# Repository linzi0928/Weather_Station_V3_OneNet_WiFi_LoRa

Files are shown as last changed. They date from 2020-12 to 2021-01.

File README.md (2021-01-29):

# Weather_Station_V3_OneNet_WiFi_LoRa
STM32+ESP8266+SX1278+Onenet的户外气象站制作
================
中文版制作教程请下拉。   
This repository contains all design files for an outdoor weather station. It can detect temperature, humidity, atmospheric pressure, TVOC, CO2, PM2.5, UV intensity and its own voltage. Then it can upload these parameters to the OneNet IoT platform through Wifi and http protocols. At the same time, it also provides the source code of an Android APP which can connect the OneNet platform and show these parameters.  
The design is divided into three parts:  
* Outdoor Data Collector
* Indoor Data Display&Uploader
* Android APP  
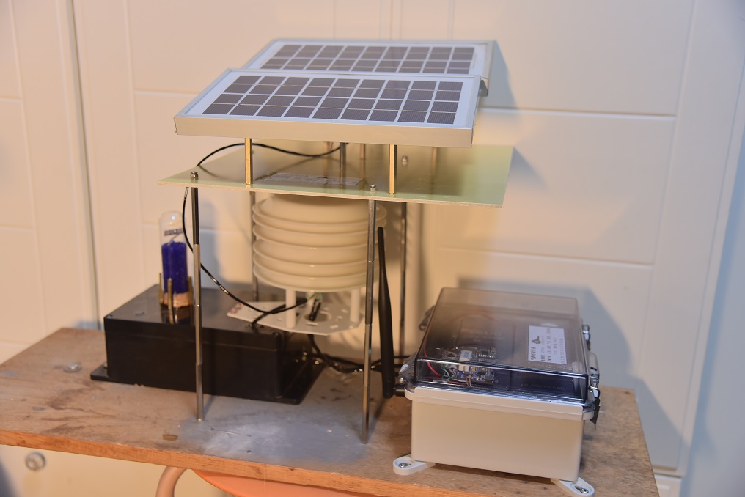
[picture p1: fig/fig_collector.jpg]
Data Collector
  
# Outdoor Data Collector  
This is the most important part of this design. Sensors and controllers are as follows:  
* STM32L051C8T6 as main controller.  
* SX1278 sends data to the indoor uploader.  
* Two LS Ultra Capacitor 2.8V 3000F in serial to storage the power.  
* Two 9V 3Watts Solar Panels in parallel to power up the whole system.  
* BME680 to get temperature, humidity and atmospheric pressure.  
* SGP30 to get CO2 and TVOC.  
* VEML6070 to get UV intensity.  
* ZPH02 to get PM2.5.  
* ESP8266 to upload the data directly (Optional)  
**Schematic of Data Collector**  
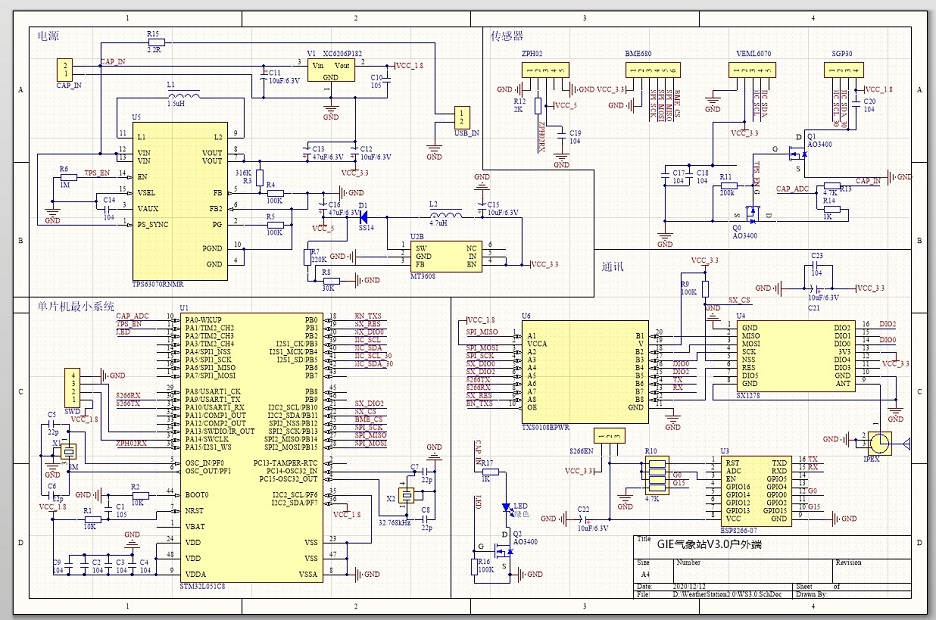
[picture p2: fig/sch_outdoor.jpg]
Schematic of Data Collector
  
**STEP 1 Collect ALL Materials!**  
Use Altium Designer to open the PCB project and check if the circuit is suitable for you. If you don't want any changes, you can directly submit the .PcbDoc files to the factory. And then compare the schematic diagram and the BOM(bill of materials) exported by AltiumDesigner to purchase components. Except the components in the BOM, you also need these:  
LS Ultra Capacitor 2.8V 3000F with protection board x2  
Outdoor waterproof box made by ABS or other reliable materials 160x210x100mm x1  
Test Tube 30x100mm(For installing UV sensor) x1  
Desiccant(For filling the test tube)  
Resin waterproof agent  
Venetian box for weather station  
M4 screws and nuts  
M4 60+6mm Stainless steel column x25  
PG7 waterproof head  x3  
Fiberglass board 300 mm * 300 mm * 3 mm x1  
Waterproof resin  
Wires and other small things  
**STEP 2 Complete the Welding of the Circuit**  
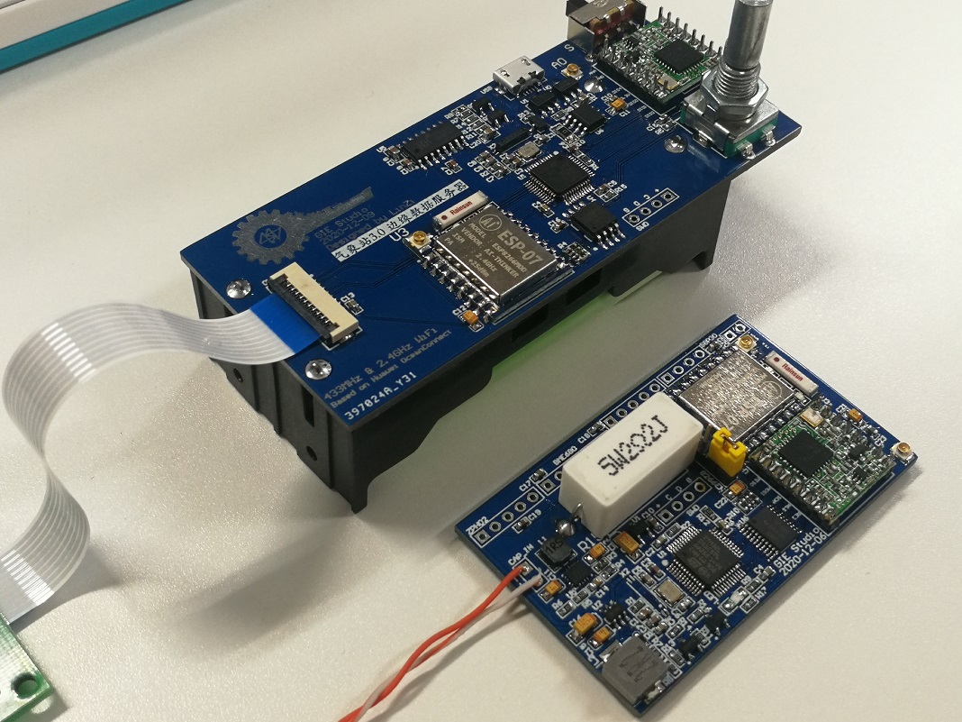
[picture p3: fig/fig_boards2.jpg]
PCBs of two part of this project
  
There is no special process for outdoor data-collector welding. The specific parameter of each component can be obtained by look at the schematic diagram.We recommend welding the chips, resistors and capacitors at first, then welding higher components, and finally welding the plug-ins, which can make the welding process more convenient.After the welding is completed, power on to test whether it is working properly. Normally, there will be abnormal work caused by improper welding.  
**STEP 3 Assembly**  
First, make four holes on the side of the box.Three of them are used to install the PG7 waterproof head and one is used to install the antenna.Be sure the holes have the right diameter.  
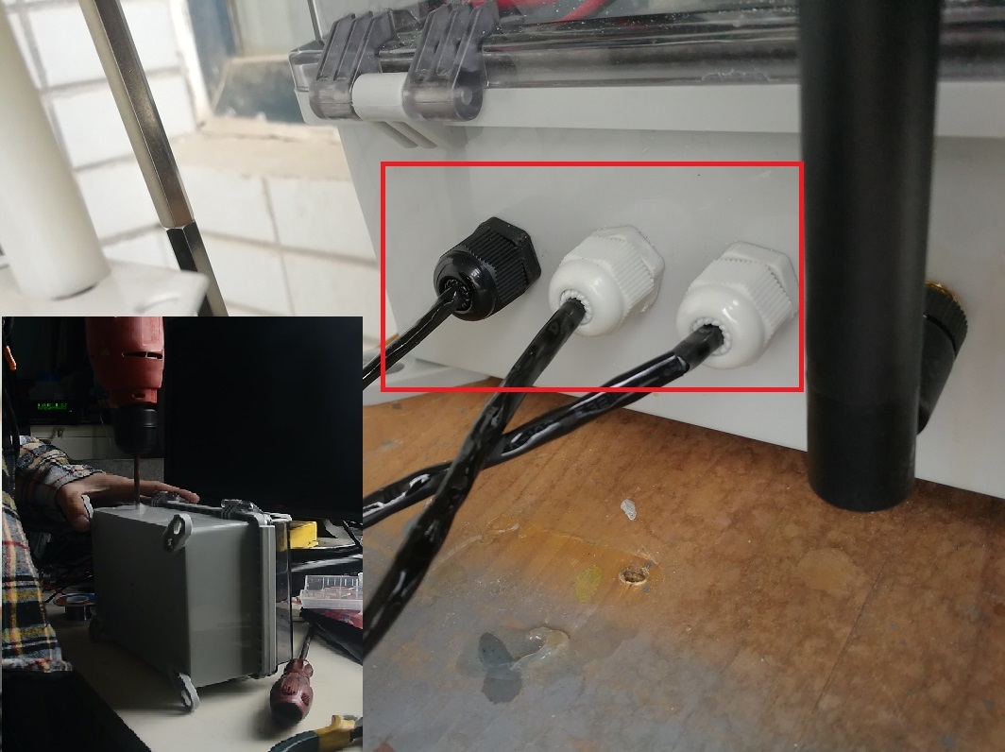
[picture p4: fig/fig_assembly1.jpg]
Make holes at the side of the box
  
Then install the protection board of the ultra capacitor and lead out the wire, and then put it into the box. Next fill up the gap between the capacitor and the box with anything you can find.     
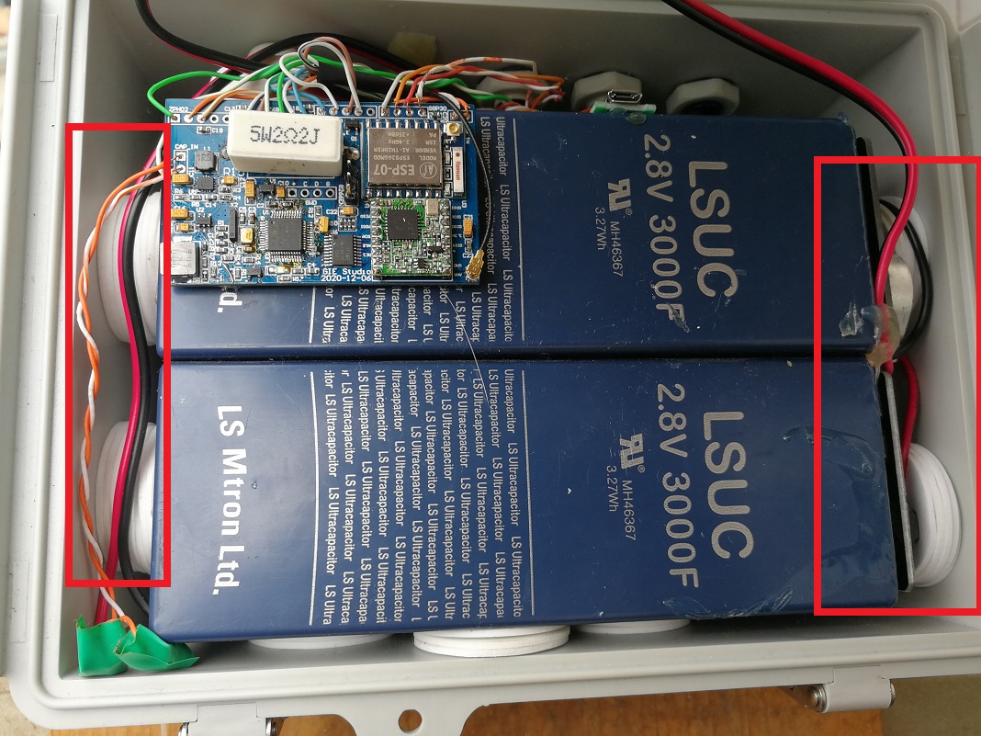
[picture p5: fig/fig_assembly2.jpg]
Install two capacitors and fill up the gap
    
Find a suitable base-plate and fix the box to it. I used a scrap wooden board as the base-plate. Then fill up the test tube using desiccant and put the wired-up UV sensor into it. Then put the PM2.5 sensor(ZPH02), BME680, SGP30 into the venetian box.  
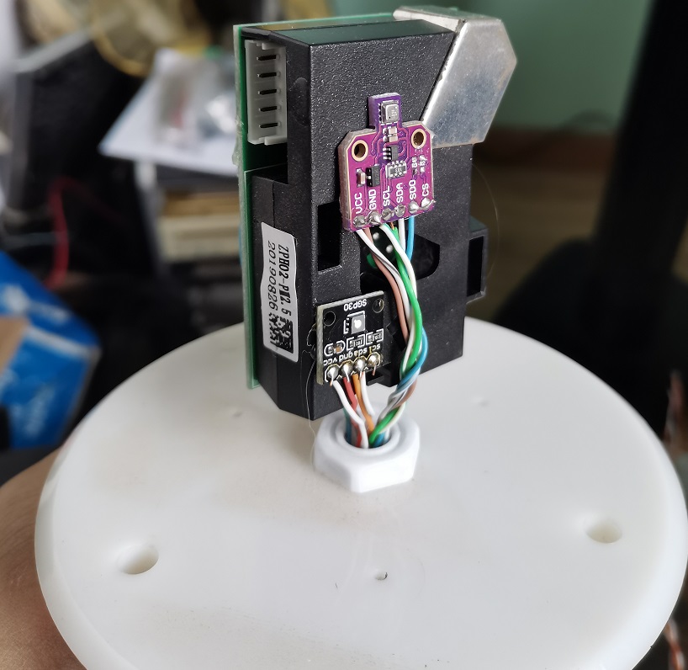
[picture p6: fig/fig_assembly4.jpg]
Install ZPH02, BME680, SGP30 into the venetian box
   
Install the test tube and the venetian box on the base-plate. In order to facilitate the installation, some things can be used to pad. For example, I used the black box left by the previous generation weather station to pad the sensors.  
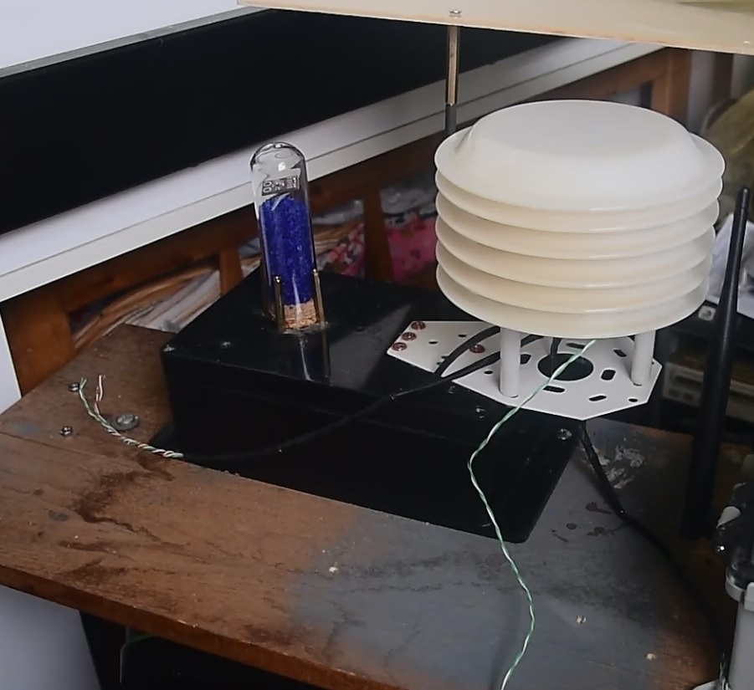
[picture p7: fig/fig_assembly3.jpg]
Install the UV sensor and venetian box
  
Then use stainless steel column to put up the fiberglass board to cover the venetian box. This is to prevent direct sunlight from interfering with the sensors in the venetian box. Finally, install the solar panel above the fiberglass board and fix it with stainless steel column. The output of the solar panel is directly paralleled to the two ends of the capacitor through a 1N5819 diode.    
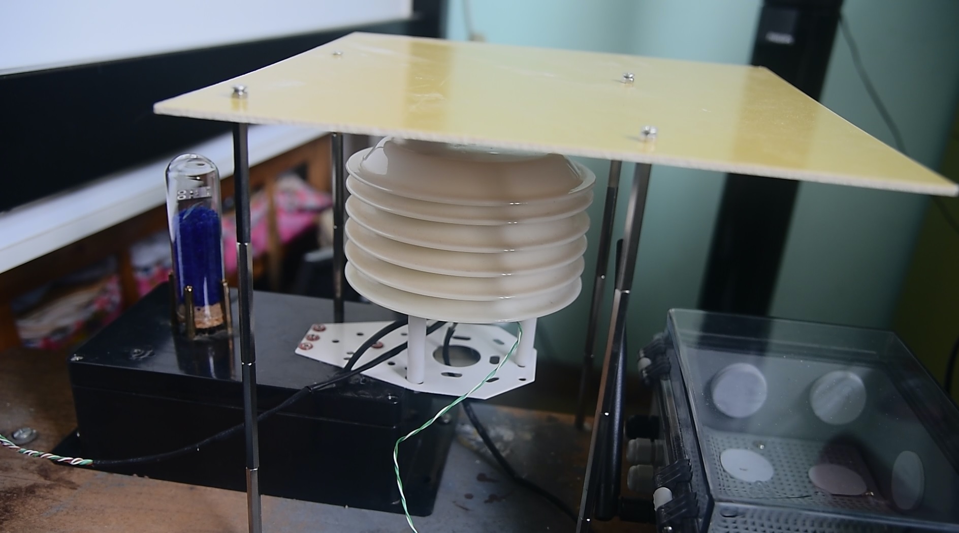
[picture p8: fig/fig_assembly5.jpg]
Install the Fiberglass board
  
**STEP 4 Program and Debug**  
Notice: Because STM32 works under 1.8V voltage in this design, you need to download the program use the full version of JLINK.  
The program is created on the MDK521 using CUBE MX. The data collector and the uploader are connected by sx1278 in 433MHz frequency band.In order to save power, when the collector completes a data acquisition of sensors, it will pack all the data and send it in 433MHz frequency band only once. So the uploader needs to listen all the time to avoid missing packets.The communication protocol between collector and uploader is shown in the chart below.  

|  Byte  | 0-3 | 4-7 | 8-11 | 12-15 | 16-16 | 17-20 | 21-22 | 23-24 | 25-26 | 27-30 |
| :----: | :----: | :----: | :----: | :----: | :----: | :----: | :----: | :----: | :----: | :----: |
| Content | Temperature | Humidity | Pressure | Gas resistance | VOC Level | PM2.5 | UV | CO2 | TVOC | Voltage |
| Type | Float | Float | Float | Float | u8 | u32 | u16 | u16 | u16 | Float |
  
# Indoor Data Display&Uploader
This part of this design can recieve data packages from the outdoor collector. And then upload these data to OneNet using http protocol. In addition, the data can be stored in  128Mbit memory and displayed on a 256x64 OLED screen in real time. After connecting to the computer through USB, the data can be exported through serial port. Controller and other components are as follows:  
* STM32F103CBT6 as main controller.  
* SX1278 receive data from the outdoor collector.  
* Two 18650 lithium batteries to storage the power.    
* ESP8266 to connect the OneNet platform.  
* 256x64 OLED screen to display the data.  
* CH340C to connect the computer.  
* 25Q128 flash to store the data.  
* 3D printing shell.  
**Schematic of Data Uploader**  
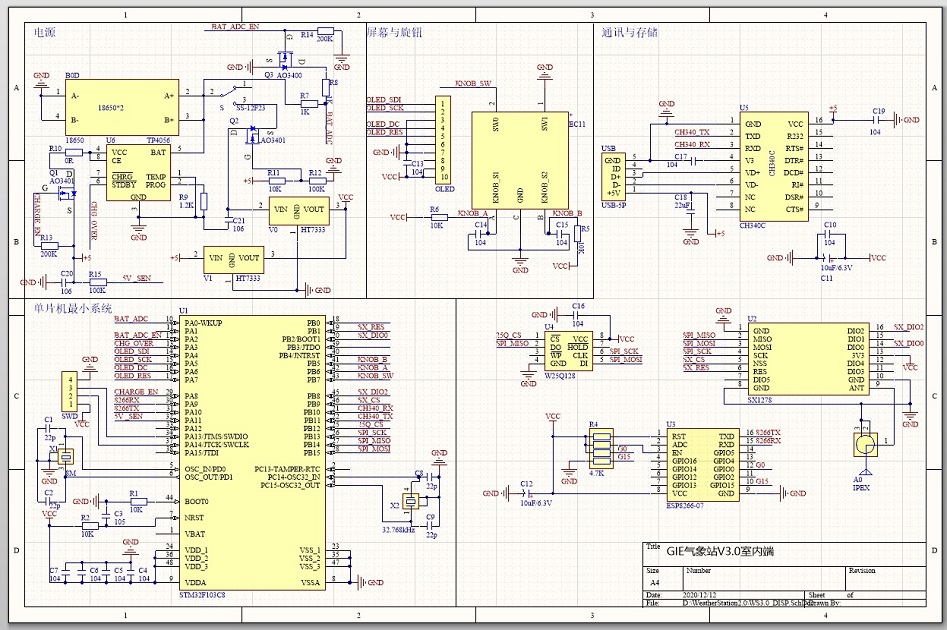
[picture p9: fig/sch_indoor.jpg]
Schematic of Data Uploader
  
**STEP 1 Collect ALL Materials!**  
The steps to export BOM are the same as before. In addition to the materials in the BOM, the following items need to be prepared:  
18650 lithium battery x2  
256x64 OLED screen x1  
IPEX-SMA cable x2  
Knob handle for ec11 x1  
10pin 1mm 10cm reverse FPC cable  x1  
3D printing shell(design file also in this repository  
M3 screws and nuts  
Dupont lines  
**STEP 2 Complete the Welding of the Circuit**  
Same as the data-collector...  
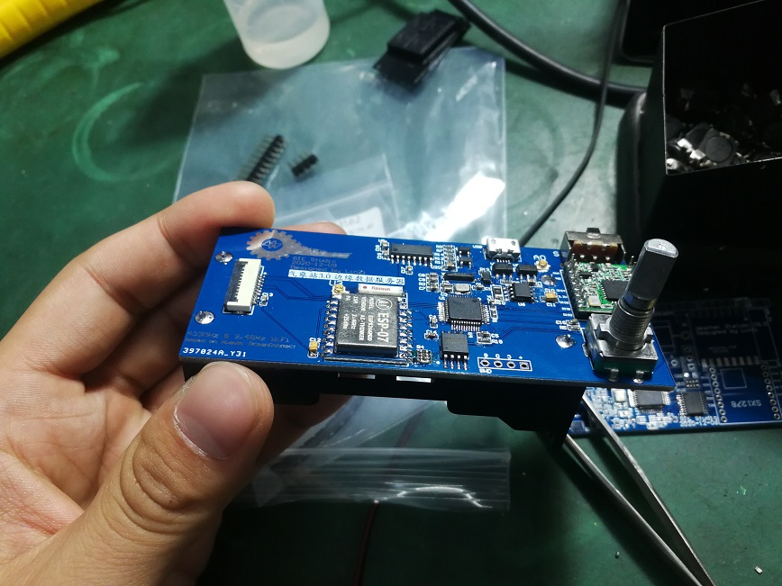
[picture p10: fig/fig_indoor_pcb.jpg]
PCB of indoor uploader
  
**STEP 3 Program and Debug**  
Same as the data collector, the program is also created on the MDK521 use CUBE MX and we also recommend using JLINK to download and debug the program. If you do not want to add or remove any functions, you can directly download the program into the microcontroller.  
Wifi name, password and various information required to access the OneNet platform can be written through the USB serial port using AT command.Use a micro usb cable to connect the computer and the uploader. If you are using this kind of USB serial port for the first time, you may need to install the CH340 driver.Then open a serial port assistant and select the port number that the uploader is connected to. Then you can send AT commands through serial port assistant to write configuration information.All available AT commands are shown below(Note: All commands need to end with a newline (\r\n)):  
* AT+EXP  
This command is used to query and export the weather information stored in the uploader.  
Using AT+EXP?, you can query the storage address of the latest data. The address indicates the location where the weather information is stored in the flash, starting from 0x10000 (0x00000-0x10000 are reserved for storing configuration information). Each time a piece of weather information is stored, the address will increase by 64 bytes, which is Hexadecimal 0x40, for example, when the first message is stored, the latest address will change from 0x10000 to 0x10040, and so on.  
Using AT+EXP=<addr> you can export all weather information starting from this address to the latest. If addr=10000, all weather information can be exported.(Example: AT+EXP=10000)  
* AT+ERS  
This command can be used to erase all weather information. For safety, you need to type and send this command twice to complete the deletion.  
* AT+CWJAP  
This command can be used to configure the ssid and password of the Wifi connected to the uploader.  
Using AT+CWJAP=<WiFi SSID>,<WiFi password> to achieve it. For example:AT+CWJAP=TP-Link-xxx,88888888. Note that the SSID cannot be longer than 21 letters, and the password cannot be longer than 20 letters, otherwise the configuration will fail.  
* AT+CMSET  
This command can be used to set the access information of the OneNet platform.  
Using AT+CMSET=<dev_id>,<API-key> to achieve it. For example:AT+CMSET=657284563,SkFGTtTMpEFf=xG580jwowTZ9r0=.
  
**STEP 4 Assembly**  
Because it is not easy to modify the circuit or program after assembly, we recommend installing it into the shell after debugging.You can paint the shell to your desired color before assembling if you like. In addition, you can also use the DuPont cable to lead the debug port to the side of the circuit board, so that you can easily modify the program even after assembly.  
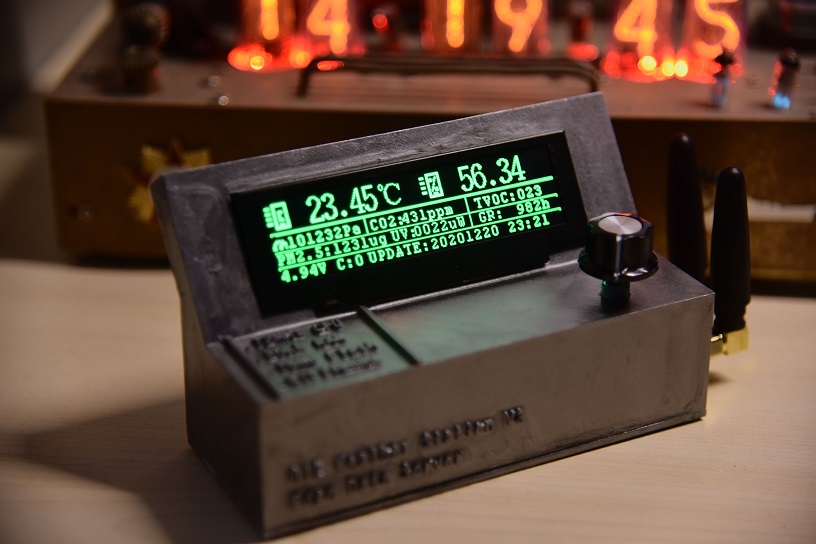
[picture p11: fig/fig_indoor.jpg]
indoor uploader
  
The first step in assembly is to install the screen. First, insert the FPC cable into the screen, and then fold the FPC into a 90-degree angle so that it can be drawn out from the side. Then put the screen into the shell diagonally upwards, so that the PCB of the screen is stuck in the gap at the top of the shell and allow the screen expose completely. Then use hot melt glue to simply fix the bottom and sides of the screen.  
Then insert the circuit board with the battery into the shell. After installing the back plate, the assembly is complete.
# Android APP
This APP can connect the OneNet and get the data. It is built on Android Studio. Please understand that it only has Chinese version currently.
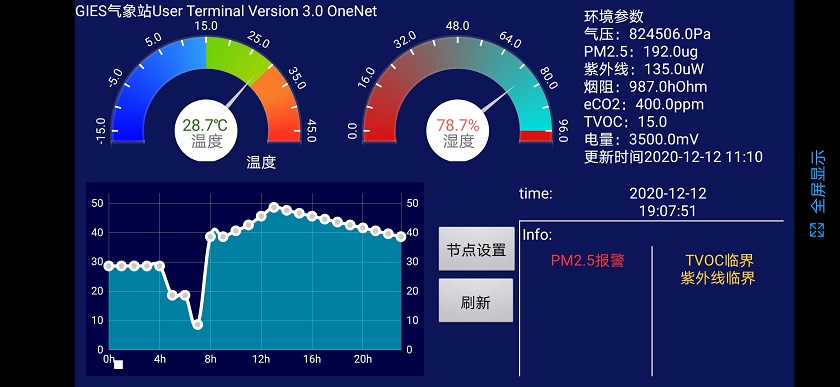
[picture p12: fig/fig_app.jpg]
APP
  
#
STM32+ESP8266+SX1278+Onenet的户外气象站制作
=============
此仓库包含室外气象站的所有设计文件。可检测温度、湿度、大气压、TVOC、CO2、PM2.5、紫外线和自身电压。然后可以通过Wifi和http协议将这些参数上传到中国移动OneNet物联网平台。同时还提供了一个Android APP的源代码，可以从OneNet平台获取气象站的数据。  
设计分为三部分：
* 室外数据采集器  
* 室内数据显示上传器  
* Android应用程序  
Data Collector  
# 户外采集端  
户外采集端是本设计的主体部分，传感器和控制器如下：
*主控制器STM32L051C8T6  
*SX1278发送数据到室内中继  
*两个串联的LSUC的超级电容2.8V 3000F  
*两块9伏3瓦的太阳能电池板并联为整个系统供电  
*BME680获得温度、湿度和大气压  
*SGP30获取CO2和TVOC  
*VEML6070获取紫外线强度  
*ZPH02获取PM2.5  
*ESP8266直接上传数据（可选）  
**户外采集端原理图**  
Schematic of Data Collector  
**步骤一 收集材料**  
使用Altium Designer打开PCB项目，检查电路是否合适。如果不想做任何更改，可以直接将.PcbDoc文件发到淘宝上做pcb的厂家。然后使用AltiumDesigner导出的元器件清单（BOM）采购元件。除此之外，还需要如下零部件：  
LSUC超级电容2.8V 3000F，以及保护板  x2  
户外防水盒160x210x100mm x1  
试管30x100mm（用于安装紫外线传感器）x1  
干燥剂（用于填充试管）  
树脂防水剂  
气象站用百叶盒子  
M4螺丝和螺母
M4 60+6mm不锈钢柱x25
PG7防水头x3  
玻璃纤维板 300x300x3 mm x1  
PCB保护树脂
电线和其他小零件  
**步骤二 电路焊接**  
PCBs of two part of this project  
焊接上没什么好说的，每个元件的具体型号可以通过查看原理图获得。建议先焊接芯片、电阻、电容，再焊接较高的元器件，最后焊接插件，这样可以使焊接过程更加方便。然后通电测试是否正常工作，一般情况下都会有焊接不当导致的异常。  
**步骤三 组装**  
首先，在防水盒的侧面打四个孔，其中的三个用于安装PG7防水头，一个用于安装天线，根据具体情况决定孔的正确直径。  
Make holes at the side of the box  
然后装上超级电容的保护板，引出导线，然后放入盒内，用你能找到的任何东西填满电容和盒子之间的空隙。   
Install two capacitors and fill up the gap    
找一个合适的底板，把盒子固定在上面。我用了一块废木板做的底板。然后将燥剂倒入试管，并将连接好的紫外线传感器放入试管中，然后将PM2.5传感器（ZPH02）、BME680、SGP30放入百叶盒。   
Install ZPH02, BME680, SGP30 into the venetian box   
将试管和百叶盒安装在底板上。为了便于安装，有些东西可以用来垫，比如我这里用上一代气象站留下的黑盒子来把这俩垫起来。  
Install the UV sensor and venetian box  
为了防止阳光直射干扰百叶盒中的传感器，需要用不锈钢柱搭玻璃纤维板盖住百叶盒。然后将太阳能板安装在玻璃纤维板上方，并用不锈钢柱固定，太阳能电池板的输出通过一个1N5819二极管直接并联到电容的两端。最后用放水树脂将所有可能漏水、腐蚀的地方涂好即可。  
Install the Fiberglass board  
**步骤四 程序下载与调试**  
注意：由于本设计中STM32工作在1.8V电压下，因此需要使用完整版的JLINK下载程序。
程序是使用CubeMX在MDK521上创建的。户外采集端和室内中继以433MHz频段sx1278通信，为了省电，当采集端完成传感器的数据采集后只会在433MHz频段发送一次，所以室内中继端需要一直监听以避免遗漏包。采集器和上传器之间的通信协议如下表所示。

|  字节  | 0-3 | 4-7 | 8-11 | 12-15 | 16 | 17-20 | 21-22 | 23-24 | 25-26 | 27-30 |
| :----: | :----: | :----: | :----: | :----: | :----: | :----: | :----: | :----: | :----: | :----: |
| 内容 | 温度 | 湿度 | 气压 | 烟阻 | VOC等级 | PM2.5 | 紫外线 | 二氧化碳 | TVOC | 电压 |
| 类型 | Float | Float | Float | Float | u8 | u32 | u16 | u16 | u16 | Float |  
# 室内数据中继与显示端
这部分设计可以接收来自室外采集端的数据包。然后使用http协议将这些数据上传到OneNet。此外，数据还将存储到128Mbit闪存中，并实时显示在256x64的oled屏幕上，通过USB连接到计算机后，可以通过串口导出数据。控制器及其它部件方案如下：  
* STM32F103CBT6为主控  
* SX1278从室外采集端接收数据  
* 两个18650锂电池供电  
* ESP8266连接OneNet平台  
* 256x64 OLED屏幕显示数据  
* CH340C连接电脑  
* 25Q128闪存存储数据  
* 3D打印外壳  
**室内数据中继端原理图**  
Schematic of Data Uploader  
**步骤一 收集材料**  
导出BOM表的步骤与前面相同。除了BOM表中的材料外，还需要准备以下元件：  
18650 锂电池 x2  
256x64 OLED 屏幕 x1  
IPEX-SMA 转接线 x2  
ec11旋钮帽 x1  
10pin 1mm 10cm 反向 FPC线  x1  
3D 打印外壳（设计文件同样在仓库中）  
M3螺丝与螺母  
母对母杜邦线  
**步骤二 电路焊接**  
与数据采集端相同...  
PCB of indoor uploader  
**步骤三 程序下载与调试**  
与数据采集器相同，该程序也是在MDK521上创建的，使用cubemx，建议使用JLINK下载和调试该程序。如果不想添加或删除任何功能，可以直接将程序下载到微控制器中。    
Wifi名称、密码和访问OneNet平台所需的各种信息都可以通过USB串口AT命令修改，用micro USB线连接电脑，如果是第一次使用这种USB串口，可能需要安装CH340驱动，然后打开串口调试助手并选择连接到的端口号，然后就可以通过串口助手发送AT命令来修改配置了。全部可用的AT命令如下所示（注意：所有命令都需要以换行符（\r\n））结尾：  

* AT+EXP  
此命令用于查询和导出数据中继端中存储的天气信息。  
使用AT+EXP?，可以查询最新数据的存储地址，地址指示天气信息存储在闪存中的位置，从0x10000开始（0x00000-0x10000保留用于存储配置信息），每次存储一条天气信息时，地址都会增加64个字节，即十六进制的0x40，例如存储第一条信息时，最新地址会从0x10000变为0x10040，以此类推。  
使用AT+EXP=<addr>可以将从该地址开始的所有天气信息导出。如果addr=10000，则可以导出所有天气信息（例如：AT+EXP=10000）  
  
* AT+ERS  
此命令可用于删除所有天气信息。为了安全起见，需要并发送此命令两次以完成删除。  
  
* AT+CWJAP
此命令可用于配置连接Wifi的名称和密码。  
使用AT+CWJAP=<WiFi SSID>，<WiFi password>实现。示例：AT+CWJAP=TP-Link xxx,88888888. 注意wifi名称不能超过21个字母，密码不能超过20个字母，否则配置将失败。  
* AT+CMSET  
此命令可用于设置OneNet平台的访问信息。  
使用AT+CMSET=<dev\uid>，<API key>实现。示例：AT+CMSET=657284563,SkFGTtTMpEFf=xG580jwowTZ9r0=
**步骤四 组装**  
由于在组装后修改电路或程序不容易，我们建议在组装后将其安装到外壳中调试。组装前可以把外壳漆成你想要的颜色。此外，还可以使用杜邦线将调试端口引到电路板的一侧，这样即使在组装之后也可以方便地修改程序。   
indoor uploader  
组装的第一步是安装屏幕，首先将FPC插入屏幕，然后将FPC折叠成90度角，以便从侧面拉出，然后将屏幕对角向上放入外壳中，使屏幕的PCB卡在外壳顶部的缝隙中，使屏幕完全露出。然后用热熔胶简单地固定屏幕的底部和侧面，  
然后将带电池的电路板装入外壳，安装背板后即可完成组装。
# Android APP
这个应用程序可以连接OneNet并随时获取气象站数据，基于Android Studio建立，打包好的APK和源代码本仓库均有提供。
APP

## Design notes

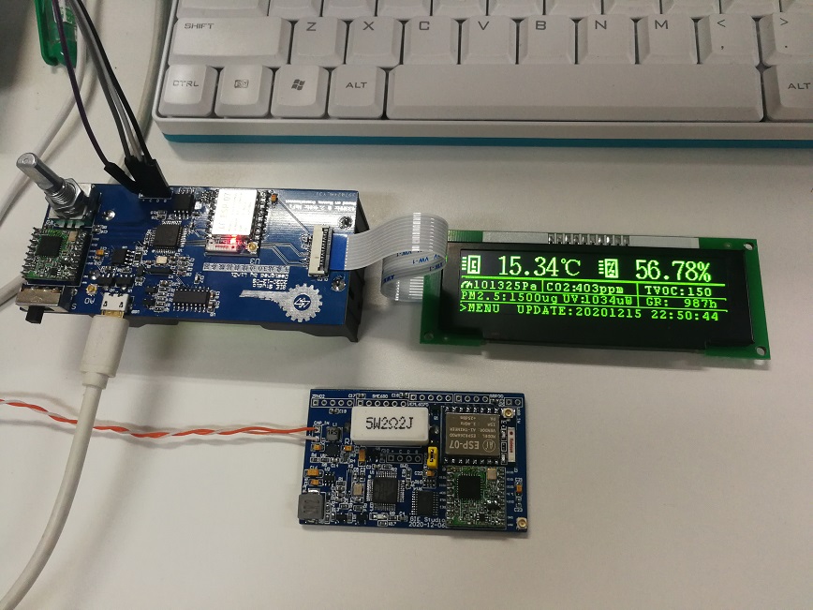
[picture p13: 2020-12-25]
fig/fig_boards.jpg

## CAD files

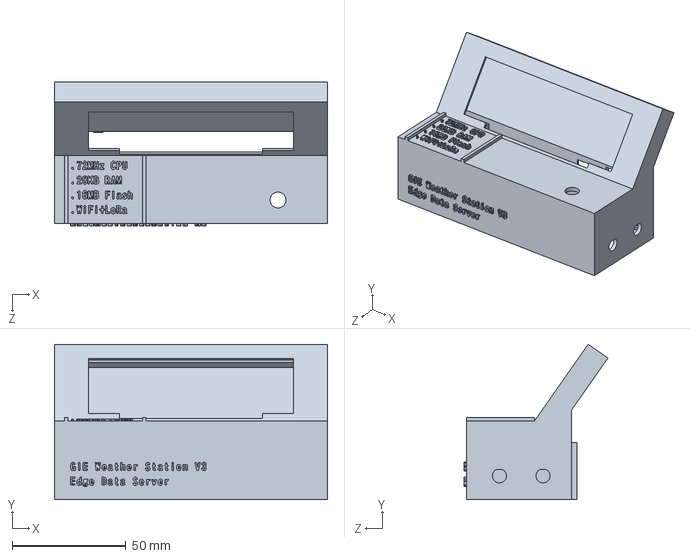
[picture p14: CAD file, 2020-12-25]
3D Model of Shell/Main_3D_Part.SLDPRT
120.0 x 68.3 x 63.3 mm

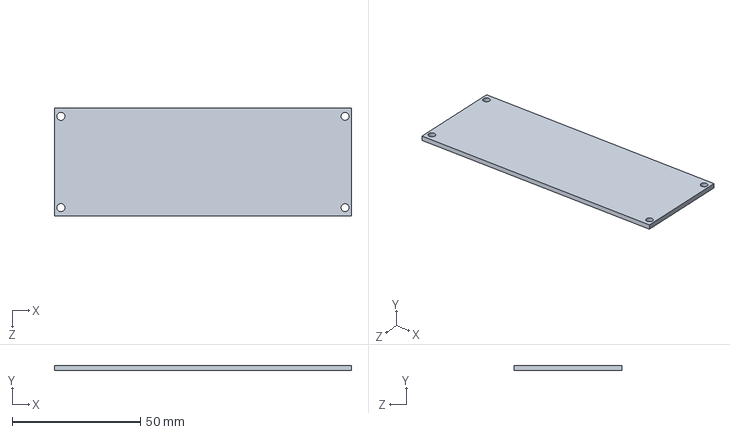
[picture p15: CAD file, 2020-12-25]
3D Model of Shell/Back_shell_3D_Part.SLDPRT
116.0 x 2.00 x 42.2 mm

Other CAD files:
3D Model of Shell/shell_3D_Part.STL
3D Model of Shell/Back_shell_3D_Part.STL

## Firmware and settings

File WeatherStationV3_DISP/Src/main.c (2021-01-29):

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
/* Includes ------------------------------------------------------------------*/
#include "main.h"
#include "adc.h"
#include "iwdg.h"
#include "rtc.h"
#include "spi.h"
#include "usart.h"
#include "gpio.h"

/* USER CODE BEGIN Includes */
#include "sx12xxEiger.h"
#include "string.h"
#include "stdlib.h"
#include "user_para_init.h"
/* USER CODE END Includes */


/* USER CODE BEGIN PV */
RTC_DateTypeDef sdatestructure;
RTC_TimeTypeDef stimestructure;
unsigned char CM_Onenet_devID[24]="657283663";//默认设备ID
unsigned char CM_Onenet_api_key[40]="SkVLFtTMpEFf=xG581jwowTZ9q0=";//默认API-Key
unsigned char API_Base_addr[]="183.230.40.33";//默认接入地址
unsigned char Wifi_SSID[21]="GIE_Studio_NetCenter";//默认Wifi名
unsigned char Wifi_password[20]="7104021730114";//默认Wifi密码
int curr_addr_flash=0;//当前最新数据所在地址尾
//flash(W25Q128)的第0 block用于存放配置信息：
unsigned char default_setting[]={
	0xaf,//0-0  0xaf起始位
	0x00,0x77,0xEF,0x4F,0x53,//1-5  最新数据时间戳
	0x01,0x00,0x00,//6-8  当前最新数据所在地址，去除第0 block的配置信息后地址从0x10000写起
	0x00,0x00,0x00,0x00,0x00,0x00,0x00,0x00,0x00,0x00,0x00,0x00,0x00,0x00,0x00,0x00,0x00,0x00,0x00,0x00,0x00,0x00,//9-30 Wifi名,以0x00结尾
	0x00,0x00,0x00,0x00,0x00,0x00,0x00,0x00,0x00,0x00,0x00,0x00,0x00,0x00,0x00,0x00,0x00,0x00,0x00,0x00,0x00,0x00,//31-52 Wifi密码，以0x00结尾
	0x00,0x00,0x00,0x00,0x00,0x00,0x00,0x00,
	0x00,0x00,0x00,0x00,0x00,0x00,0x00,0x00,//53-67 中移OneNet平台设备ID，以0x00结尾
	0x00,0x00,0x00,0x00,0x00,0x00,0x00,0x00,
	0x00,0x00,0x00,0x00,0x00,0x00,0x00,0x00,
	0x00,0x00,0x00,0x00,0x00,0x00,0x00,0x00,
	0x00,0x00,0x00,0x00,0x00,0x00,0x00,0x00,
	0x00,0x00,0x00,0x00,0x00,0x00,0x00,0x00,//68-108 中移OneNet平台设备接入API-Key，以0x00结尾
	0x01,0xB5,//109-110 LoRa默认通信频率（437MHz）
	0x00,0x01,0x00,//111-113  当前已上传最新数据所在地址
};
/* USER CODE END PV */

void SystemClock_Config(void);
/* USER CODE BEGIN PFP */
extern void OLED_Init(void);
/* USER CODE END PFP */

/**
  * @brief  The application entry point.
  * @retval int
  */
int main(void)
{
  /* MCU Configuration--------------------------------------------------------*/

  /* Reset of all peripherals, Initializes the Flash interface and the Systick. */
  HAL_Init();

  /* Configure the system clock */
  SystemClock_Config();

  /* Initialize all configured peripherals */
  MX_GPIO_Init();
  MX_USART1_UART_Init();
  MX_USART3_UART_Init();
  MX_RTC_Init();
  MX_SPI2_Init();
  MX_ADC1_Init();
  MX_IWDG_Init();
  /* USER CODE BEGIN 2 */
	HAL_UART_Receive_IT(&huart1, &TempChar, 1);
	HAL_UART_Receive_IT(&huart3, &TempChar2, 1);//打开串口中断
	OLED_Init();
	HAL_GPIO_WritePin(GPIOA, GPIO_PIN_2, GPIO_PIN_SET);//打开ADC输入
	HAL_GPIO_WritePin(GPIOA, GPIO_PIN_8, GPIO_PIN_SET);//关闭充电
	charge_flag=1;
	BoardInit( );
	Radio = RadioDriverInit( );
	Radio->Init( );
	Radio->StartRx( );
	BSP_W25Qx_Init();
	load_config();
	Show_HZ12_12(90,0,0,0,2);Asc6_12(132,0,"V3.0");//气象站V3
	Draw_Rectangle(0xaa,1,0,255,13,14);
	print_pc("GIE Weather Station Edge Data Server\r\n",sizeof("GIE Weather Station Edge Data Server\r\n"));
	Asc6_12(38,52,"GIE Studio 2020-12-15");
	Asc5_8(0,20,"WiFi Connecting...");
	print_pc("WiFi Connecting...\r\n",sizeof("WiFi Connecting...\r\n"));
	unsigned char temp_bufferw[30];
	sprintf((char *)temp_bufferw,"SSID:%s",Wifi_SSID);
	print_pc(temp_bufferw,sizeof(temp_bufferw)-1);
	Asc5_8(0,29,temp_bufferw);
	HAL_IWDG_Refresh(&hiwdg);
	if(ESP8266_Init())//初始化ESP8266，并连接wifi
	{
		Asc5_8(0,39,"WiFi Connect error, save data local");
		print_pc("\r\nWiFi Connect error, save data local\r\n",sizeof("\r\nWiFi Connect error, save data local\r\n"));
	}
	else
	{
		Asc5_8(0,39,"WiFi Connected");
		print_pc("\r\nWiFi Connected\r\n",sizeof("\r\nWiFi Connected\r\n"));
	}
	unsigned char vol_dis[]="0.00V";
	Show_HZ12_12(150,20,0,6,6);Show_HZ12_12(166,20,0,8,8);//电压：
	while(i<30)
		{
			voltage_get();
			sprintf((char*)vol_dis,"%.2lfV",read_adc);
			Asc6_12(188,20,vol_dis);
			HAL_Delay(100);
			i++;
		}
		i=0;
	Fill_RAM(0x00);
	OLED_WR_Byte(0xAF,0); //	Display On
  HAL_RTC_GetTime(&hrtc, &stimestructure, RTC_FORMAT_BIN);
  HAL_RTC_GetDate(&hrtc, &sdatestructure, RTC_FORMAT_BIN);
	if(sdatestructure.Year==0)//日期未设置，联网对时
	{
		HAL_IWDG_Refresh(&hiwdg);
		Asc5_8(0,0,"Local Time not set");
		print_pc("Local Time not set\r\n",sizeof("Local Time not set\r\n"));
		if(!HTTP_Time_Get(pack_time))
		{
			Asc5_8(0,8,"Net Time Get");
			print_pc("Net Time Get\r\n",sizeof("Net Time Get\r\n"));
			print_pc(pack_time,31);print_pc("\r\n",2);
			HTTP_Time_Convert((char *)pack_time);
			HAL_Delay(1000);
			Fill_RAM(0x00);
			OLED_WR_Byte(0xAF,0); //	Display On
		}
		else
		{
			Asc5_8(0,8,"Net Time Get Failed");
			print_pc("Net Time Get Failed\r\n",sizeof("Net Time Get Failed\r\n"));
			HAL_Delay(1000);
			Fill_RAM(0x00);
			OLED_WR_Byte(0xAF,0); //	Display On
		}
	}
		//以上为启动界面，以下为主信息显示屏初始化
		Refresh_Addr();
		Read_recent_rec();
		Package_Decoding();
		Main_UI_Refresh();
		print_pc("System Boot Complete\r\n",sizeof("System Boot Complete\r\n"));
		print_pc("Listening at 437MHz for Weather Packages\r\n",sizeof("Listening at 437MHz for Weather Packages\r\n"));
  /* USER CODE END 2 */

  /* Infinite loop */
  /* USER CODE BEGIN WHILE */
  while (1)
  {
		while( Radio->Process( ) == RF_RX_DONE)//从1278读取接收完成标志，如果这个包接收完成则进入
		{
		for(ixx=0;ixx<BUFFER_SIZE;ixx++)
		px[ixx] = 0;
		Radio->GetRxPacket( px, ( uint16_t* )&BufferSize );//依次取出缓冲区内容
		Rssi1278=(int)SX1276LoRaReadRssi();
		Radio->StartRx();
		Package_Decoding();
		if(!data_check())//检查数据是否合理
		{
				Fill_RAM(0x00);
				OLED_WR_Byte(0xAF,0); //	Display On
				Asc5_8(0,0,"Incoming Package...Analyzing...");
				//Asc5_8(0,0,"Incoming Package...Analyzing...");
				print_pc("Package Received\r\n",sizeof("Package Received\r\n"));
			
				upload_user();		//上传数据	
				Save_Local_Data();			//本地保存数据
		}
			else
		{
				print_pc("Data Invalid\r\n",sizeof("Data Invalid\r\n"));
				Read_recent_rec();
				Package_Decoding();
		}
			Main_UI_Refresh();
			memset(px,0x00,sizeof(px));
		}
		charge_check();
		COM_Handler();
		if(EncoderKey_Scan()==1)//扫描编码器进入菜单
		{
			Enter_Menu_UI();
		}
    /* USER CODE END WHILE */

    /* USER CODE BEGIN 3 */
		HAL_IWDG_Refresh(&hiwdg);

  }
  /* USER CODE END 3 */
}

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
/* USER CODE BEGIN 4 */
void COM_Handler(void)//AT命令响应与执行
{
	char* strx1=0,*strx2=0;
	unsigned char send_buffer[128];
	unsigned char read_buffer[64];
	int read_addr=0;//串口批量导出起始地址
	if(USART3_RX_STA&0x8000)
	{
		USART3_RX_STA=0;
		memset(send_buffer,0x00,sizeof(send_buffer));
		strx1=strstr((const char*)USART3_RX_BUF,"AT");
		if(strx1==0)
		{
			print_pc(USART3_RX_BUF,sizeof(USART3_RX_BUF));print_pc("\r\n",2);
			print_pc("Invalid Command\r\n",sizeof("Invalid Command\r\n"));
			memset(USART3_RX_BUF,0x00,sizeof(USART3_RX_BUF));
			return;
		}
		else
		{
			strx2=strstr((const char*)USART3_RX_BUF,"AT+");
			if(strx2==0)
			{
				print_pc("AT\r\n",sizeof("AT\r\n"));
				memset(USART3_RX_BUF,0x00,sizeof(USART3_RX_BUF));
				return;
			}
			else
			{
				strx1=strstr((const char*)USART3_RX_BUF,"EXP");
				if(strx1!=0)
				{
					if(*(strx1+3)=='?')//AT+EXP?查询当前最新数据的存储地址
					{
						print_pc(USART3_RX_BUF,sizeof(USART3_RX_BUF));print_pc("\r\n",2);
						sprintf((char*)send_buffer,"CURR_ADDR:%08X\r\n",curr_addr_flash);//AT+EXP=10000查询某地址之后的所有数据，16进制
						print_pc(send_buffer,20);
					}
					else if(*(strx1+3)=='=')
					{
						if(curr_addr_flash==0x10000)
						{
							print_pc(USART3_RX_BUF,sizeof(USART3_RX_BUF));print_pc("\r\n",2);
							print_pc("No data to export\r\n",sizeof("No data to export\r\n"));
						}
						strx1+=4;
						read_addr=ahextoi(strx1);
						if(read_addr>=0x10000&&read_addr<=0x1000000)
						{
							uint8_t time_store[6];
							read_addr=0x40*(read_addr/0x40);
							print_pc(USART3_RX_BUF,sizeof(USART3_RX_BUF));print_pc("\r\n",2);
							for(;read_addr<curr_addr_flash;read_addr+=0x40)
							{
								if(read_addr>=curr_addr_flash)
								{
									break;
								}
								BSP_W25Qx_Read(read_buffer,read_addr,0x40);
								Package_Decoding_Com(read_buffer);
								memcpy(time_store,read_buffer+32,6);
								sprintf((char *)send_buffer,"%.1fC %.1f%% %.0fPa %dug %duW %dppm %dppb 20%02d-%02d-%02d %02d:%02d:%02d %.2fV",
									env_send_com.temp,env_send_com.humi,env_send_com.pressure,env_send_com.dust_25,env_send_com.uvv,
									env_send_com.co2_eq_ppm,env_send_com.tvoc_ppb,time_store[0],time_store[1],time_store[2],time_store[3],time_store[4],time_store[5],env_send_com.batval);
								print_pc(send_buffer,sizeof(send_buffer));print_pc("\r\n",2);
								memset(send_buffer,0x00,sizeof(send_buffer));
							}
						}
						else
						{
							print_pc(USART3_RX_BUF,sizeof(USART3_RX_BUF));print_pc("\r\n",2);
							print_pc("Invalid Address",sizeof("Invalid Address"));
						}
					}
					
				}
				else
				{
					strx1=strstr((const char*)USART3_RX_BUF,"ERS");//AT+ERS删除所有存储的气象信息
					if(strx1!=0)
					{
						if(ers_f_flag==0)
						{
							print_pc(USART3_RX_BUF,sizeof(USART3_RX_BUF));print_pc("\r\n",2);
							print_pc("Type again to comfirm the erase of whole chip\r\n",sizeof("Type again to comfirm the erase of whole chip\r\n"));
							ers_f_flag=1;
						}
						else
						{
							print_pc(USART3_RX_BUF,sizeof(USART3_RX_BUF));print_pc("\r\n",2);
								print_pc("Working...\r\n",sizeof("Working...\r\n"));
								BSP_W25Qx_Erase_Chip();
								curr_addr_flash=0x10000;
								default_setting[6]=curr_addr_flash>>16;
								default_setting[7]=(curr_addr_flash&0xff00)>>8;
								default_setting[8]=(curr_addr_flash&0x00ff);
								BSP_W25Qx_Write(default_setting, 0x00,114);
								print_pc("Erase done!\r\n",sizeof("Erase done!\r\n"));
							ers_f_flag=0;
						}
					}
					else
					{
						strx1=strstr((const char*)USART3_RX_BUF,"CWJAP=");//AT+CWJAP=HUAWEI Mate9,7104021730114设置Wifi的SSID和密码
						if(strx1!=0)
						{
							strx1+=6;
							strx2=strstr((const char*)USART3_RX_BUF,",");
							if(strx2==0)
							{
								print_pc(USART3_RX_BUF,sizeof(USART3_RX_BUF));print_pc("\r\n",2);
								print_pc("Invalid Command\r\n",sizeof("Invalid Command\r\n"));
								memset(USART3_RX_BUF,0x00,sizeof(USART3_RX_BUF));
								return;
							}
							else
							{
								memset(Wifi_SSID,0x00,sizeof(Wifi_SSID));
								memcpy(Wifi_SSID,strx1,strx2-strx1);
								strx2+=1;
								strx2=strstr((const char*)USART3_RX_BUF,",");
								memset(Wifi_password,0x00,sizeof(Wifi_password));
								memcpy(Wifi_password,strx2+1,20);
								BSP_W25Qx_Erase_Block(0x00);
								memcpy(default_setting+9,Wifi_SSID,sizeof(Wifi_SSID));
								default_setting[9+sizeof(Wifi_SSID)-1]=0x00;
								memcpy(default_setting+31,Wifi_password,sizeof(Wifi_password));
								default_setting[31+sizeof(Wifi_password)-1]=0x00;
								BSP_W25Qx_Write(default_setting, 0x00,sizeof(default_setting));
								sprintf((char *)send_buffer,"New WiFi Set OK\r\nSSID:%s Pass:%s\r\nReboot to take effect\r\n",Wifi_SSID,Wifi_password);
								print_pc(USART3_RX_BUF,sizeof(USART3_RX_BUF));print_pc("\r\n",2);
								print_pc(send_buffer,sizeof(send_buffer));
							}
						}
						else
						{
							strx1=strstr((const char*)USART3_RX_BUF,"RST");	//AT+RST重启
							if(strx1!=0)
							{
								print_pc(USART3_RX_BUF,sizeof(USART3_RX_BUF));print_pc("\r\n",2);
								print_pc("System Reset\r\n",sizeof("System Reset\r\n"));
								__set_FAULTMASK(1); NVIC_SystemReset();
							}
							else
							{
								strx1=strstr((const char*)USART3_RX_BUF,"CMSET");	//AT+CMSET=657283663,SkVLFtTMpEFf=xG581jwowTZ9q0=设置设备ID和API-Key
								if(strx1!=0)
									{
										strx2=0;
										strx1=0;
										strx1=strstr((const char*)USART3_RX_BUF,"?");
										if(strx1!=0)
										{
											print_pc(USART3_RX_BUF,sizeof(USART3_RX_BUF));print_pc("\r\n",2);
											sprintf((char *)send_buffer,"DevID:%s API-Key:%s\r\n",CM_Onenet_devID,CM_Onenet_api_key);
											print_pc(send_buffer,sizeof(send_buffer));
											memset(USART3_RX_BUF,0x00,sizeof(USART3_RX_BUF));
											return;
										}
										strx1=strstr((const char*)USART3_RX_BUF,"=");
										strx1+=1;
										strx2=strstr((const char*)strx1,",");
										if(strx2!=0)
										{
											memset(CM_Onenet_devID,0x00,sizeof(CM_Onenet_devID));
											memcpy(CM_Onenet_devID,strx1,strx2-strx1);
											strx1=strx2+1;
											memset(CM_Onenet_api_key,0x00,sizeof(CM_Onenet_api_key));
											memcpy(CM_Onenet_api_key,strx1,40);
											BSP_W25Qx_Erase_Block(0x00);
											memcpy(default_setting+53,CM_Onenet_devID,24);
											default_setting[53+sizeof(CM_Onenet_devID)-1]=0x00;		
											memcpy(default_setting+68,CM_Onenet_api_key,40);
											default_setting[68+sizeof(CM_Onenet_api_key)-1]=0x00;	
											BSP_W25Qx_Write(default_setting, 0x00,sizeof(default_setting));
											print_pc("New Dev ID and API Key Set OK,Reboot to take effect\r\n",sizeof("New Dev ID and API Key Set OK,Reboot to take effect\r\n"));
											sprintf((char *)send_buffer,"DevID:%s API-Key:%s\r\n",CM_Onenet_devID,CM_Onenet_api_key);
											print_pc(USART3_RX_BUF,sizeof(USART3_RX_BUF));print_pc("\r\n",2);
											print_pc(send_buffer,sizeof(send_buffer));
										}
										else
										{
											print_pc("Invalid DevID\r\n",sizeof("Invalid DevID\r\n"));
										}
									}
								else
								{
									print_pc("Invalid Command\r\n",sizeof("Invalid Command\r\n"));
								}
							}
						}
					}
				}
			}
		}
		memset(USART3_RX_BUF,0x00,sizeof(USART3_RX_BUF));
	}
}
void Package_Decoding(void)//解码数据包
{	
	if(px[0]==0&&px[1]==0&&px[2]==0&&px[3]==0&&px[4]==0&&px[5]==0&&px[6]==0&&px[7]==0&&px[8]==0)
		return;
		temp=buffer2float(px);
		humi=buffer2float(px+4);
		pressure=buffer2float(px+8);
		gas_r=buffer2float(px+12);
		voc_level=px[16];
		dust_25=px[17]<<24 | px[18]<<16 | px[19]<<8 | px[20]; 
		uvv=px[21]<<8 | px[22];
		co2_eq_ppm=px[23]<<8 | px[24];
		tvoc_ppb=px[25]<<8 | px[26];
		batval=buffer2float(px+27);
}
void Package_Decoding_Com(uint8_t input[])//串口导出时的数据包解码
{	
		env_send_com.temp=buffer2float(input);
		env_send_com.humi=buffer2float(input+4);
		env_send_com.pressure=buffer2float(input+8);
		env_send_com.gas_r=buffer2float(input+12);
		env_send_com.dust_25=input[17]<<24 | input[18]<<16 | input[19]<<8 | input[20]; 
		env_send_com.uvv=input[21]<<8 | input[22];
		env_send_com.co2_eq_ppm=input[23]<<8 | input[24];
		env_send_com.tvoc_ppb=input[25]<<8 | input[26];
		env_send_com.batval=buffer2float(input+27);
}
void Main_UI_Refresh(void)//主界面数据刷新
{
	unsigned char dis_buffer[32];
	if(!data_check())//检查数据是否合理
	{
		Draw_Rectangle(0xaa,1,0,255,25,26);

		
		HZ24_24(0,0,0);//温度显示区
		sprintf((char*)dis_buffer,"%02.2f",temp);
		Asc12_24(36,0,dis_buffer);
		HZ24_24(96,0,1);
		
		
		HZ24_24(136,0,2);//湿度显示区
		sprintf((char*)dis_buffer,"%02.2f%",humi);
		Asc12_24(172,0,dis_buffer);

		Show_HZ12_12(0,29,0,12,12);//气压显示区
		sprintf((char*)dis_buffer,"%6.0fPa",pressure);
		Asc6_12(13,29,dis_buffer);
		
		Draw_Rectangle(0xaa,1,82,82,26,40);
		sprintf((char*)dis_buffer,"%03dppm",co2_eq_ppm);
		Asc6_12(87,29,"CO2:");
		Asc6_12(112,29,dis_buffer);
		
		Draw_Rectangle(0xaa,1,175,175,26,40);
		sprintf((char*)dis_buffer,"%03d",tvoc_ppb);
		Asc6_12(180,29,"TVOC:");
		Asc6_12(220,29,dis_buffer);
		
		Draw_Rectangle(0xaa,1,0,255,40,40);
		
		Asc6_12(0,41,"PM2.5:");
		sprintf((char*)dis_buffer,"%04dug",dust_25);
		Asc6_12(50,41,dis_buffer);
		
		Asc6_12(100,41,"UV:");
		sprintf((char*)dis_buffer,"%04duW",uvv);
		Asc6_12(120,41,dis_buffer);
		
		Draw_Rectangle(0xaa,1,175,175,40,52);
		
		Asc6_12(180,41,"GR:");
		sprintf((char*)dis_buffer,"%.0fh",gas_r);
		Asc6_12(216,41,dis_buffer);
		
		Draw_Rectangle(0xaa,1,0,255,52,52);
		
		sprintf((char*)dis_buffer,"UPT:%02d%02d%02d %02d:%02d",year,mon,day,hour,min);
		Asc6_12(100,54,dis_buffer);
		sprintf((char*)dis_buffer,"%.2fV",batval);
		Asc6_12(0,54,dis_buffer);
		sprintf((char*)dis_buffer,"%ddb",Rssi1278);
		Asc6_12(50,54,dis_buffer);
	}
}
void voltage_get(void)//本机电压获取
{
	int time_out=0,adc_raw;
	HAL_ADC_Start(&hadc1);
	HAL_ADC_GetValue(&hadc1);    
	while(HAL_ADC_PollForConversion(&hadc1, 0xff)!=HAL_OK)
	{
		time_out++;
		if(time_out>10000)
			return;
	}
	adc_raw=HAL_ADC_GetValue(&hadc1);
	read_adc=((float)adc_raw/65535.0)*3.3*70-2.75;//换算为电压
}
void charge_check(void)//控制充电开始与结束
{
	if(charge_com_flag==1)
	{
		HAL_GPIO_WritePin(GPIOA, GPIO_PIN_8, GPIO_PIN_RESET);
		charge_flag=1;
		return;
	}
	voltage_get();
		if(read_adc>4.00&&charge_flag==1)
		{
			flag_40++;
		}
		else if(flag_40>0&&read_adc<=4.00)
		{
			flag_40--;
		}
		if(flag_40>50&&charge_flag==1)
		{
			
			HAL_GPIO_WritePin(GPIOA, GPIO_PIN_8, GPIO_PIN_SET);//关闭充电
			charge_flag=0;
		}
		if(read_adc<3.95&&charge_flag==0)
		{
			flag_395++;
		}
		else if(flag_395>0&&read_adc>3.95&&charge_flag==0)
		{
			flag_395--;
		}
		if(flag_395>50)
		{
			HAL_GPIO_WritePin(GPIOA, GPIO_PIN_8, GPIO_PIN_RESET);//开启充电
			charge_flag=1;
			
		}
}
int data_check(void)//数据检查
{
	if(temp<60&&temp>-50&&humi>0&&humi<100&&pressure>50000&&pressure<110000&&batval>0&&batval<10)
		return 0;
	else
		return 1;
}
void load_config(void)//加载配置
{
	unsigned char write_buffer[256];
	BSP_W25Qx_Read(write_buffer, 0x00, 0xff);//读取配置block，仅第0page有效
	if(write_buffer[0]!=0xaf)//首次开机写入默认配置
	{
		BSP_W25Qx_Erase_Block(0x00);
		memcpy(default_setting+9,Wifi_SSID,sizeof(Wifi_SSID));
		default_setting[9+sizeof(Wifi_SSID)-1]=0x00;
		memcpy(default_setting+31,Wifi_password,sizeof(Wifi_password));
		default_setting[31+sizeof(Wifi_password)-1]=0x00;
		memcpy(default_setting+53,CM_Onenet_devID,sizeof(CM_Onenet_devID));
		default_setting[53+sizeof(CM_Onenet_devID)-1]=0x00;		
		memcpy(default_setting+68,CM_Onenet_api_key,sizeof(CM_Onenet_api_key));
		default_setting[68+sizeof(CM_Onenet_api_key)-1]=0x00;		
		curr_addr_flash=0x10000;
		BSP_W25Qx_Write(default_setting, 0x00,sizeof(default_setting));
	}
	else//非首次开机读取flash中的配置
	{
		memset(Wifi_SSID,0x00,sizeof(Wifi_SSID));
		memcpy(Wifi_SSID,write_buffer+9,sizeof(Wifi_SSID));
		memset(Wifi_password,0x00,sizeof(Wifi_password));
		memcpy(Wifi_password,write_buffer+31,sizeof(Wifi_password));
		memset(CM_Onenet_devID,0x00,sizeof(CM_Onenet_devID));
		memcpy(CM_Onenet_devID,write_buffer+53,sizeof(CM_Onenet_devID));
		memset(CM_Onenet_api_key,0x00,sizeof(CM_Onenet_api_key));
		memcpy(CM_Onenet_api_key,write_buffer+68,sizeof(CM_Onenet_api_key));
		curr_addr_flash=(write_buffer[6]<<16)|(write_buffer[7]<<8)|(write_buffer[8]);
		memcpy(default_setting,write_buffer,sizeof(default_setting));
	}
	
}
void Read_recent_rec(void)//读取flash中最新的数据
{
	unsigned char temp_data[64],time_store[6];
	if(curr_addr_flash==0x10000)
		return;
	BSP_W25Qx_Read(temp_data,curr_addr_flash-0x40,0x40);
	memcpy(px,temp_data,32);
	memcpy(time_store,temp_data+32,6);
	hex2time(time_store);
}
void Save_Local_Data(void)
{
	if(temp==22.22&&humi==88.88&&pressure==100000&&gas_r==1111&&batval==9.9)//避免保存无意义数据
		return;
	unsigned char time_store[6];
	unsigned char temp_pack[1];
	memset(Save_Package,0x00,64);
	memcpy(Save_Package,px,32);
	time2hex(time_store);
	memcpy(Save_Package+32,time_store,6);
	BSP_W25Qx_Read(temp_pack,curr_addr_flash,sizeof(temp_pack));
	while(temp_pack[0]!=0xff)
	{
		curr_addr_flash+=64;
		BSP_W25Qx_Read(temp_pack,curr_addr_flash,sizeof(temp_pack));
	}
	BSP_W25Qx_Write(Save_Package,curr_addr_flash,sizeof(Save_Package));
	BSP_W25Qx_Read(Save_Package,curr_addr_flash,sizeof(Save_Package));
	curr_addr_flash+=64;
	default_setting[6]=(curr_addr_flash&0xff0000)>>16;
	default_setting[7]=(curr_addr_flash&0xff00)>>8;
	default_setting[8]=curr_addr_flash&0x00ff;
	BSP_W25Qx_Erase_Block(0x00);
	BSP_W25Qx_Write(default_setting, 0x00,sizeof(default_setting));
}
void Refresh_Addr(void)
{
	unsigned char temp_pack[1];
	BSP_W25Qx_Read(temp_pack,curr_addr_flash,sizeof(temp_pack));
		while(temp_pack[0]!=0xff)
	{
		curr_addr_flash+=64;
		BSP_W25Qx_Read(temp_pack,curr_addr_flash,sizeof(temp_pack));
	}
	default_setting[6]=(curr_addr_flash&0xff0000)>>16;
	default_setting[7]=(curr_addr_flash&0xff00)>>8;
	default_setting[8]=curr_addr_flash&0x00ff;
	BSP_W25Qx_Erase_Block(0x00);
	BSP_W25Qx_Write(default_setting, 0x00,sizeof(default_setting));
}
void time2hex(unsigned char *output)//将时间转换为存储序列
{
		HAL_RTC_GetTime(&hrtc, &stimestructure, RTC_FORMAT_BIN);
		HAL_RTC_GetDate(&hrtc, &sdatestructure, RTC_FORMAT_BIN);
    output[0]=sdatestructure.Year;
		year=2000+output[0];
    output[1]=sdatestructure.Month;
		mon=output[1];
    output[2]=sdatestructure.Date;
		day=output[2];
    output[3]=stimestructure.Hours;
		hour=output[3];
    output[4]=stimestructure.Minutes;
		min=output[4];
		output[5]=stimestructure.Seconds;
		sec=output[5];
}
void hex2time(unsigned char *input)//将存储的时间取出
{
    year=input[0]+2000;
		mon= input[1];
		day= input[2];
		hour=input[3];
		min= input[4];	
		sec= input[5];				 
}
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

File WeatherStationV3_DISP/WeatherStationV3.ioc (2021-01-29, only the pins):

Mcu.UserName=STM32F103C8Tx
PA0-WKUP.Signal=ADCx_IN0
PA1.Signal=GPIO_Output
PA10.Signal=USART1_RX
PA11.Signal=GPIO_Output
PA13.Signal=SYS_JTMS-SWDIO
PA14.Signal=SYS_JTCK-SWCLK
PA2.Signal=GPIO_Output
PA3.Signal=GPIO_Input
PA4.Signal=GPIO_Output
PA5.Signal=GPIO_Output
PA6.Signal=GPIO_Output
PA7.Signal=GPIO_Output
PA8.Signal=GPIO_Output
PA9.Signal=USART1_TX
PB1.Signal=GPIO_Output
PB10.Signal=USART3_TX
PB11.Signal=USART3_RX
PB12.Signal=GPIO_Output
PB13.Signal=SPI2_SCK
PB14.Signal=SPI2_MISO
PB15.Signal=SPI2_MOSI
PB2.Signal=GPIO_Input
PB5.Signal=GPXTI5
PB6.Signal=GPIO_Input
PB7.Signal=GPIO_Input
PB8.Signal=GPIO_Input
PB9.Signal=GPIO_Output
PC14-OSC32_IN.Signal=RCC_OSC32_IN
PC15-OSC32_OUT.Signal=RCC_OSC32_OUT
PD0-OSC_IN.Signal=RCC_OSC_IN
PD1-OSC_OUT.Signal=RCC_OSC_OUT

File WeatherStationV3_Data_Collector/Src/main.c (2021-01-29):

/**
  ******************************************************************************
  * @file           : main.c
  * @brief          : Main program body
  ******************************************************************************
  ** This notice applies to any and all portions of this file
  * that are not between comment pairs USER CODE BEGIN and
  * USER CODE END. Other portions of this file, whether 
  * inserted by the user or by software development tools
  * are owned by their respective copyright owners.
  *
  * COPYRIGHT(c) 2021 STMicroelectronics
  *
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
  ******************************************************************************
  */
/* Includes ------------------------------------------------------------------*/
#include "main.h"
#include "stm32l0xx_hal.h"
#include "adc.h"
#include "iwdg.h"
#include "rtc.h"
#include "spi.h"
#include "usart.h"
#include "gpio.h"

/* USER CODE BEGIN Includes */
#include "string.h"
//#include "nbiot.h"
//#include "hexstring.h"
#include "stdlib.h"
#include "platform.h"
#include "radio.h"
extern tRadioDriver *Radio;
#define BUFFER_SIZE     32
//static uint16_t BufferSize = BUFFER_SIZE;
tRadioDriver *Radio = NULL;

unsigned char Sensors_data[BUFFER_SIZE];
char msgSend[BUFFER_SIZE*2];
/* USER CODE END Includes */


/* USER CODE BEGIN PV */
/*
GIE气象站程序V3版
硬件结构：STM32L051低功耗单片机
BME680气体传感器测量温度、湿度、气压、烟阻
ZPH02粉尘传感器测量PM2.5
VEML6070紫外线传感器测量紫外线
SGP30测量CO2和TVOC含量
SX1278模块通过LoRa发送给室内机存储和上传至中移OneNet平台，硬件上也预留有8266的口，可以直接从户外采集端上传，程序自理
低功耗运作方式：wakeup计时器每15s唤醒一次喂看门狗（28s未喂狗则重启单片机），然后立即进入STOP模式，当过去225个15s唤醒周期后发送一次数据（实测差不多为1小时一次数据）
待机状态整机电流：~4uA
工作状态整机电流：~80mA
此种配置方式搭配串联的两块2.8V 3000F超级电容，3W9V的小太阳能板在持续阴天条件下电压也不会掉。
注：如果在CUBEMX中重新生成代码，注释将全部变成乱码，请提前备份，传感器相关程序在sensors.c文件中
欢迎关注b站up主：GIE工作室，获得超多干货！
Designed by LinZi
GIE Studio 2020-12-12
*/
uint32_t dust25;//PM2.5值
uint16_t uvv;//紫外线值
float tem;//温度值
float hum;//湿度值
float press;//气压值
float gas_r;//烟阻值
float batval;//电池电量
uint32_t voc_level;//voc等级
extern u16 tvoc_ppb, co2_eq_ppm;//CO2、TVOC
uint8_t sleep_counter=0;
uint8_t wakeup_count=0;
RTC_HandleTypeDef RTCHandle;
void SystemPower_Config(void);
void Enter_STOP_mode(void);
int Package_Point=0,succ_flag=0;
int load_float2buffer(float input,unsigned char* buffer_pointer);
void voltage_get(void);
uint32_t user_offset=27000000;
extern void VEML6070_Init(void);
extern void Get_sensors(void);
extern void osDelay(uint16_t time);
extern void bme680_init_user (void);
extern void Get_680(void);
void get_resert_status(void);
/* USER CODE END PV */

void SystemClock_Config(void);
static void MX_NVIC_Init(void);

/* USER CODE BEGIN PFP */

/* USER CODE END PFP */

/**
  * @brief  The application entry point.
  *
  * @retval None
  */
int main(void)
{
  /* MCU Configuration----------------------------------------------------------*/

  /* Reset of all peripherals, Initializes the Flash interface and the Systick. */
  HAL_Init();

  /* Configure the system clock */
  SystemClock_Config();

  /* Initialize all configured peripherals */
  MX_GPIO_Init();
  MX_SPI2_Init();
  MX_RTC_Init();
  MX_ADC_Init();
  MX_USART2_UART_Init();
  MX_IWDG_Init();

  /* Initialize interrupts */
  MX_NVIC_Init();
  /* USER CODE BEGIN 2 */
		HAL_GPIO_WritePin(GPIOA,GPIO_PIN_1,GPIO_PIN_RESET);
		__PWR_CLK_ENABLE();
	  HAL_RTCEx_DeactivateWakeUpTimer(&hrtc);
		get_resert_status();
		HAL_Delay(2000);//开机等待五秒再打开各种外设，避免从看门狗复位回来后其余外设没有完成重启
		HAL_IWDG_Refresh(&hiwdg);
  while (1)
  {
	
	HAL_PWREx_EnableUltraLowPower();//使能超低功耗
  HAL_PWREx_EnableFastWakeUp();
  __HAL_RCC_WAKEUPSTOP_CLK_CONFIG(RCC_STOP_WAKEUPCLOCK_HSI);
		HAL_Delay(1000);
	//HAL_UART_Receive_IT(&huart1, (uint8_t *)aRxBuffer1, 1);
	HAL_GPIO_WritePin(GPIOA,GPIO_PIN_1,GPIO_PIN_SET);//打开3.3V稳压开关（TPS63070），为全部传感器以及无线模块供电
	HAL_GPIO_WritePin(GPIOB,GPIO_PIN_0,GPIO_PIN_SET);//打开电平转换芯片开关（TXS0108）
	HAL_Delay(1000);
	HAL_UART_Receive_IT(&huart2, (uint8_t *)aRxBuffer2, 1);
	HAL_IWDG_Refresh(&hiwdg);
	bme680_init_user ();//初始化BME680（调用官方API）
	Get_680();//获取温度、湿度、气压、烟阻数据
	BoardInit( );
	Radio = RadioDriverInit( );
	Radio->Init( );
	sleep_counter=0;
	Package_Point=0;
	succ_flag=0;
	VEML6070_Init();//初始化紫外线传感器
	SGP_Init();
  /* USER CODE END 2 */

  /* Infinite loop */
  /* USER CODE BEGIN 3 */
		
		Get_sensors();//获取传感器数据
		voltage_get();
		//tem=23.45;hum=56.34;press=101232;gas_r=982;voc_level=1;dust25=1231;uvv=22;//co2_eq_ppm=431;tvoc_ppb=23;//调试用假数据
		Package_Point+=load_float2buffer(tem,Sensors_data+Package_Point);//0-3 温度
		Package_Point+=load_float2buffer(hum,Sensors_data+Package_Point);//4-7 湿度
		Package_Point+=load_float2buffer(press,Sensors_data+Package_Point);//8-11 气压
		Package_Point+=load_float2buffer(gas_r,Sensors_data+Package_Point);//12-15 烟阻
		Sensors_data[Package_Point]=voc_level;//16 VOC等级（来自ZPH02）
		Package_Point++;
		Sensors_data[Package_Point]=dust25>>24;//17-20 PM2.5
		Sensors_data[Package_Point+1]=(dust25&0x00ff0000)>>16;
		Sensors_data[Package_Point+2]=(dust25&0x0000ff00)>>8;
		Sensors_data[Package_Point+3]=(dust25&0x000000ff);
		Package_Point+=4;
		Sensors_data[Package_Point]=uvv>>8;//21-22 紫外线
		Sensors_data[Package_Point+1]=uvv&0x00ff;
		Package_Point+=2;
		Sensors_data[Package_Point]=co2_eq_ppm>>8;//23-24 CO2
		Sensors_data[Package_Point+1]=co2_eq_ppm&0x00ff;
		Sensors_data[Package_Point+2]=tvoc_ppb>>8;//25-26 TVOC
		Sensors_data[Package_Point+3]=tvoc_ppb&0x00ff;
		Package_Point+=4;
		Package_Point+=load_float2buffer(batval,Sensors_data+Package_Point);//27-30 电容电量
		HAL_IWDG_Refresh(&hiwdg);
		Radio->SetTxPacket( Sensors_data, 32 );
		while(1)
		{
			while(Radio->Process( ) == RF_TX_DONE)
			{
				Enter_STOP_mode();//进入STOP低功耗模式
				succ_flag=1;
				//Radio->SetTxPacket( TxBuf, 32 );
			}
			if(succ_flag==1)
			{
				break;
			}
		}

  }
  /* USER CODE END 3 */

}

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
/* USER CODE BEGIN 4 */
void SystemPower_Config(void)//配置单片机各个外设，使其在低功耗模式下不会耗电
{
  GPIO_InitTypeDef GPIO_InitStructure;
	

	//HAL_UART_DeInit(&huart1);//关闭串口1
  HAL_UART_DeInit(&huart2);//关闭串口2
	HAL_SPI_DeInit(&hspi2);//关闭SPI
//	__HAL_RCC_DMA1_CLK_DISABLE();
	HAL_GPIO_WritePin(GPIOA,GPIO_PIN_1,GPIO_PIN_RESET);//失能3.3V稳压，断电全部传感器与射频模块
  /* Enable GPIOs clock */
  __HAL_RCC_GPIOA_CLK_ENABLE();
  __HAL_RCC_GPIOB_CLK_ENABLE();
  __HAL_RCC_GPIOC_CLK_ENABLE();
  __HAL_RCC_GPIOD_CLK_ENABLE();
  __HAL_RCC_GPIOH_CLK_ENABLE();

  GPIO_InitStructure.Pin = GPIO_PIN_All;//将全部端口设置为模拟输入模式避免漏电
  GPIO_InitStructure.Mode = GPIO_MODE_ANALOG;
  GPIO_InitStructure.Pull = GPIO_NOPULL;
  HAL_GPIO_Init(GPIOA, &GPIO_InitStructure); 
  HAL_GPIO_Init(GPIOB, &GPIO_InitStructure);
  HAL_GPIO_Init(GPIOC, &GPIO_InitStructure);
  HAL_GPIO_Init(GPIOD, &GPIO_InitStructure);
  HAL_GPIO_Init(GPIOH, &GPIO_InitStructure);
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

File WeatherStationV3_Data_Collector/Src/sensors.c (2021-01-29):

/*
GIE气象站程序
		本文件为传感器相关函数。
Designed by LinZi
GIE Studio 2020-02-06
*/
#include "sensors.h"
void Get_sensors(void)//传感器数据采集函数
{
	int ttt=0,tt=0;
	float co2_sum=0,tvoc_sum=0;
	Get_UV();//获取紫外线数据
	SGP_Get();
	while((!Get_dust25()||(ttt<20))&&(ttt<25))//通过串口获得PM2.5数据，反复执行20次确保数据包整齐
	{
		//HAL_Delay(500);/////////////////////////////////////////////////////////////////////////////////////////////////////////////
		HAL_IWDG_Refresh(&hiwdg);
		SGP_Get();
		if(co2_eq_ppm!=400)
		{
			co2_sum+=co2_eq_ppm;
			tvoc_sum+=tvoc_ppb;
			tt++;
		}
		ttt++;
	}
	ttt=0;
	if(tt==0)
	{
		while(ttt<20)
		{
			HAL_IWDG_Refresh(&hiwdg);
			SGP_Get();
			if(co2_eq_ppm!=400)
			{
				co2_sum=co2_eq_ppm;
				tvoc_sum=tvoc_ppb;
				tt=1;
				break;
			}
			ttt++;
		}
	}
	co2_eq_ppm=(co2_sum/(float)tt);
	tvoc_ppb=(tvoc_sum/(float)tt);
	if(co2_eq_ppm==0)
	{
		co2_eq_ppm=400;
	}
}
int Get_dust25(void)//PM2.5检测程序
{
	float dust_duty=0;
	if(USART2_RX_BUF[0]==0xff&&USART2_RX_BUF[1]==0x18)//确保数据包对齐，方便提取有效数据
	{
		dust_duty=(USART2_RX_BUF[3]*100)+USART2_RX_BUF[4];
		dust_duty/=100;
		dust25=dust_duty*8.8888f;
		voc_level=USART2_RX_BUF[7];
		return 1;//获取成功
	}
	else
		return 0;//获取失败
}
void Get_UV(void)//紫外线检测程序
{
	uvv=VEML6070_ReadValue();
}
void Get_680(void)//温度湿度气压TVOC检测程序
{
	gas_sensor.power_mode = BME680_FORCED_MODE;
	bme680_set_sensor_mode(&gas_sensor);
	HAL_Delay(2000);
	bme680_get_sensor_data(&data, &gas_sensor);//获取bme680数据
	tem=((float)(data.temperature))/100.0f;//将数据传出
	hum=((float)(data.humidity))/1000.0f;
	press=(float)data.pressure;
	gas_r=data.gas_resistance/100.0f;
	if((data.temperature<(-5000))||(data.temperature>8000)||(data.humidity>(100000))||(data.pressure>(150000))||(data.pressure<(50000)))
	{//检测数据有效性，如果不满足要求则再测一次
		gas_sensor.power_mode = BME680_FORCED_MODE;
		bme680_set_sensor_mode(&gas_sensor);
		HAL_Delay(2000);
		bme680_get_sensor_data(&data, &gas_sensor);
		tem=((float)(data.temperature))/100.0;//将数据传出
		hum=((float)(data.humidity))/1000.0;
		press=data.pressure;
		gas_r=data.gas_resistance/100;
	}
	else if(fflag==0)
	{
		fflag=1;
		gas_sensor.power_mode = BME680_SLEEP_MODE;
		bme680_set_sensor_mode(&gas_sensor);
		HAL_GPIO_WritePin(GPIOB,GPIO_PIN_12,GPIO_PIN_SET);
	}
}
void bme680_init_user (void)
{
	
//	bsec_iot_init(BSEC_SAMPLE_RATE_LP, 0.0f, user_spi_write, user_spi_read, HAL_Delay, state_load, config_load).bme680_status;
    /* You may assign a chip select identifier to be handled later */
    gas_sensor.dev_id = 0;
    gas_sensor.intf = BME680_SPI_INTF;
    gas_sensor.read = user_spi_read;
    gas_sensor.write = user_spi_write;
    gas_sensor.delay_ms = HAL_Delay;
    /* amb_temp can be set to 25 prior to configuring the gas sensor 
     * or by performing a few temperature readings without operating the gas sensor.
     */
    gas_sensor.amb_temp = 25;
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

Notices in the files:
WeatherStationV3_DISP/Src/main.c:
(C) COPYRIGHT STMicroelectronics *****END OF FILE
